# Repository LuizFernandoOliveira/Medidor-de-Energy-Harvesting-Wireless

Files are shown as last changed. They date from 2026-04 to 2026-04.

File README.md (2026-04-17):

# Medidor de Energy Harvesting Wireless




## Descrição
O Medidor de Energy Harvesting Wireless é um circuito eletrônico dedicado a realizar a coleta de dados essenciais para aplicações técnico-científicas relacionadas a Energy Harveting via TEG, PVG, RFG, HEG, WIG, PZT e TC.

<p align="center">
  Imagem1-1
</p>

---

## Descrições técnicas

- Microcontrolador: MSP430FR5949;
- Armazenamento local via micro SD card;
- Envio de dados via UART ou via BLE 5.0;
- Medições de Geradores Termoelétricos (TEG):
  - Temperatura lado Quente;
  - Temperatura lado Frio;
  - Temperatura Ambiente;
- Medições de Geradores Fotovoltaicos (PVG):
  - Medidor de Tensão DC;
  - Medidor de Iluminação;
- Medições de Geradores via Transformadores de Corrente (TCG):
  - Medidor de Tensão AC;
- Medições de Geradores Piezoelétricos (PZT):
  - Medidor de Tensão AC;
  - Medidor de aceleração triaxial;
- Medidções de Geradores Hidroelétricos (HEG):
  - Medidor de Tensão;
  - Medidor de Corrente; 
- Medições de Geradores Eólicos (WIG):
  - Medidor de Tensão;
  - Medidor de Corrente; 
- Medições de Geradores via RF (RFG):
  - Medidor de Tensão;

---

## Estrutura do repositório
Os arquivos de hardware foram desenvolvidos utilizando o KiCad 9.0.
- **`.kicad_pcb`**: Layout da placa de circuito impresso (Board).
- **`.kicad_sch`**: Esquemático eletrônico do sistema (Schematic).
- **`.kicad_pro`**: Gerenciador de projeto do KiCad (Project).

---

## Autor
**Dr. Luiz Fernando Pinto de Oliveira**

*Engenheiro Eletrônico especializado em Sistemas Embarcados e Ultra-Low Power.*
- **Website:** [FAPLO](https://faplo.webnode.page/)
- **LinkedIn:** [lfpo](https://www.linkedin.com/in/lfpo/)

---

Shield: [][cc-by-nc-nd]

This work is licensed under a
[Creative Commons Attribution-NonCommercial-NoDerivs 4.0 International License][cc-by-nc-nd].

[][cc-by-nc-nd]

[cc-by-nc-nd]: http://creativecommons.org/licenses/by-nc-nd/4.0/
[cc-by-nc-nd-image]: https://licensebuttons.net/l/by-nc-nd/4.0/88x31.png
[cc-by-nc-nd-shield]: https://img.shields.io/badge/License-CC%20BY--NC--ND%204.0-lightgrey.svg

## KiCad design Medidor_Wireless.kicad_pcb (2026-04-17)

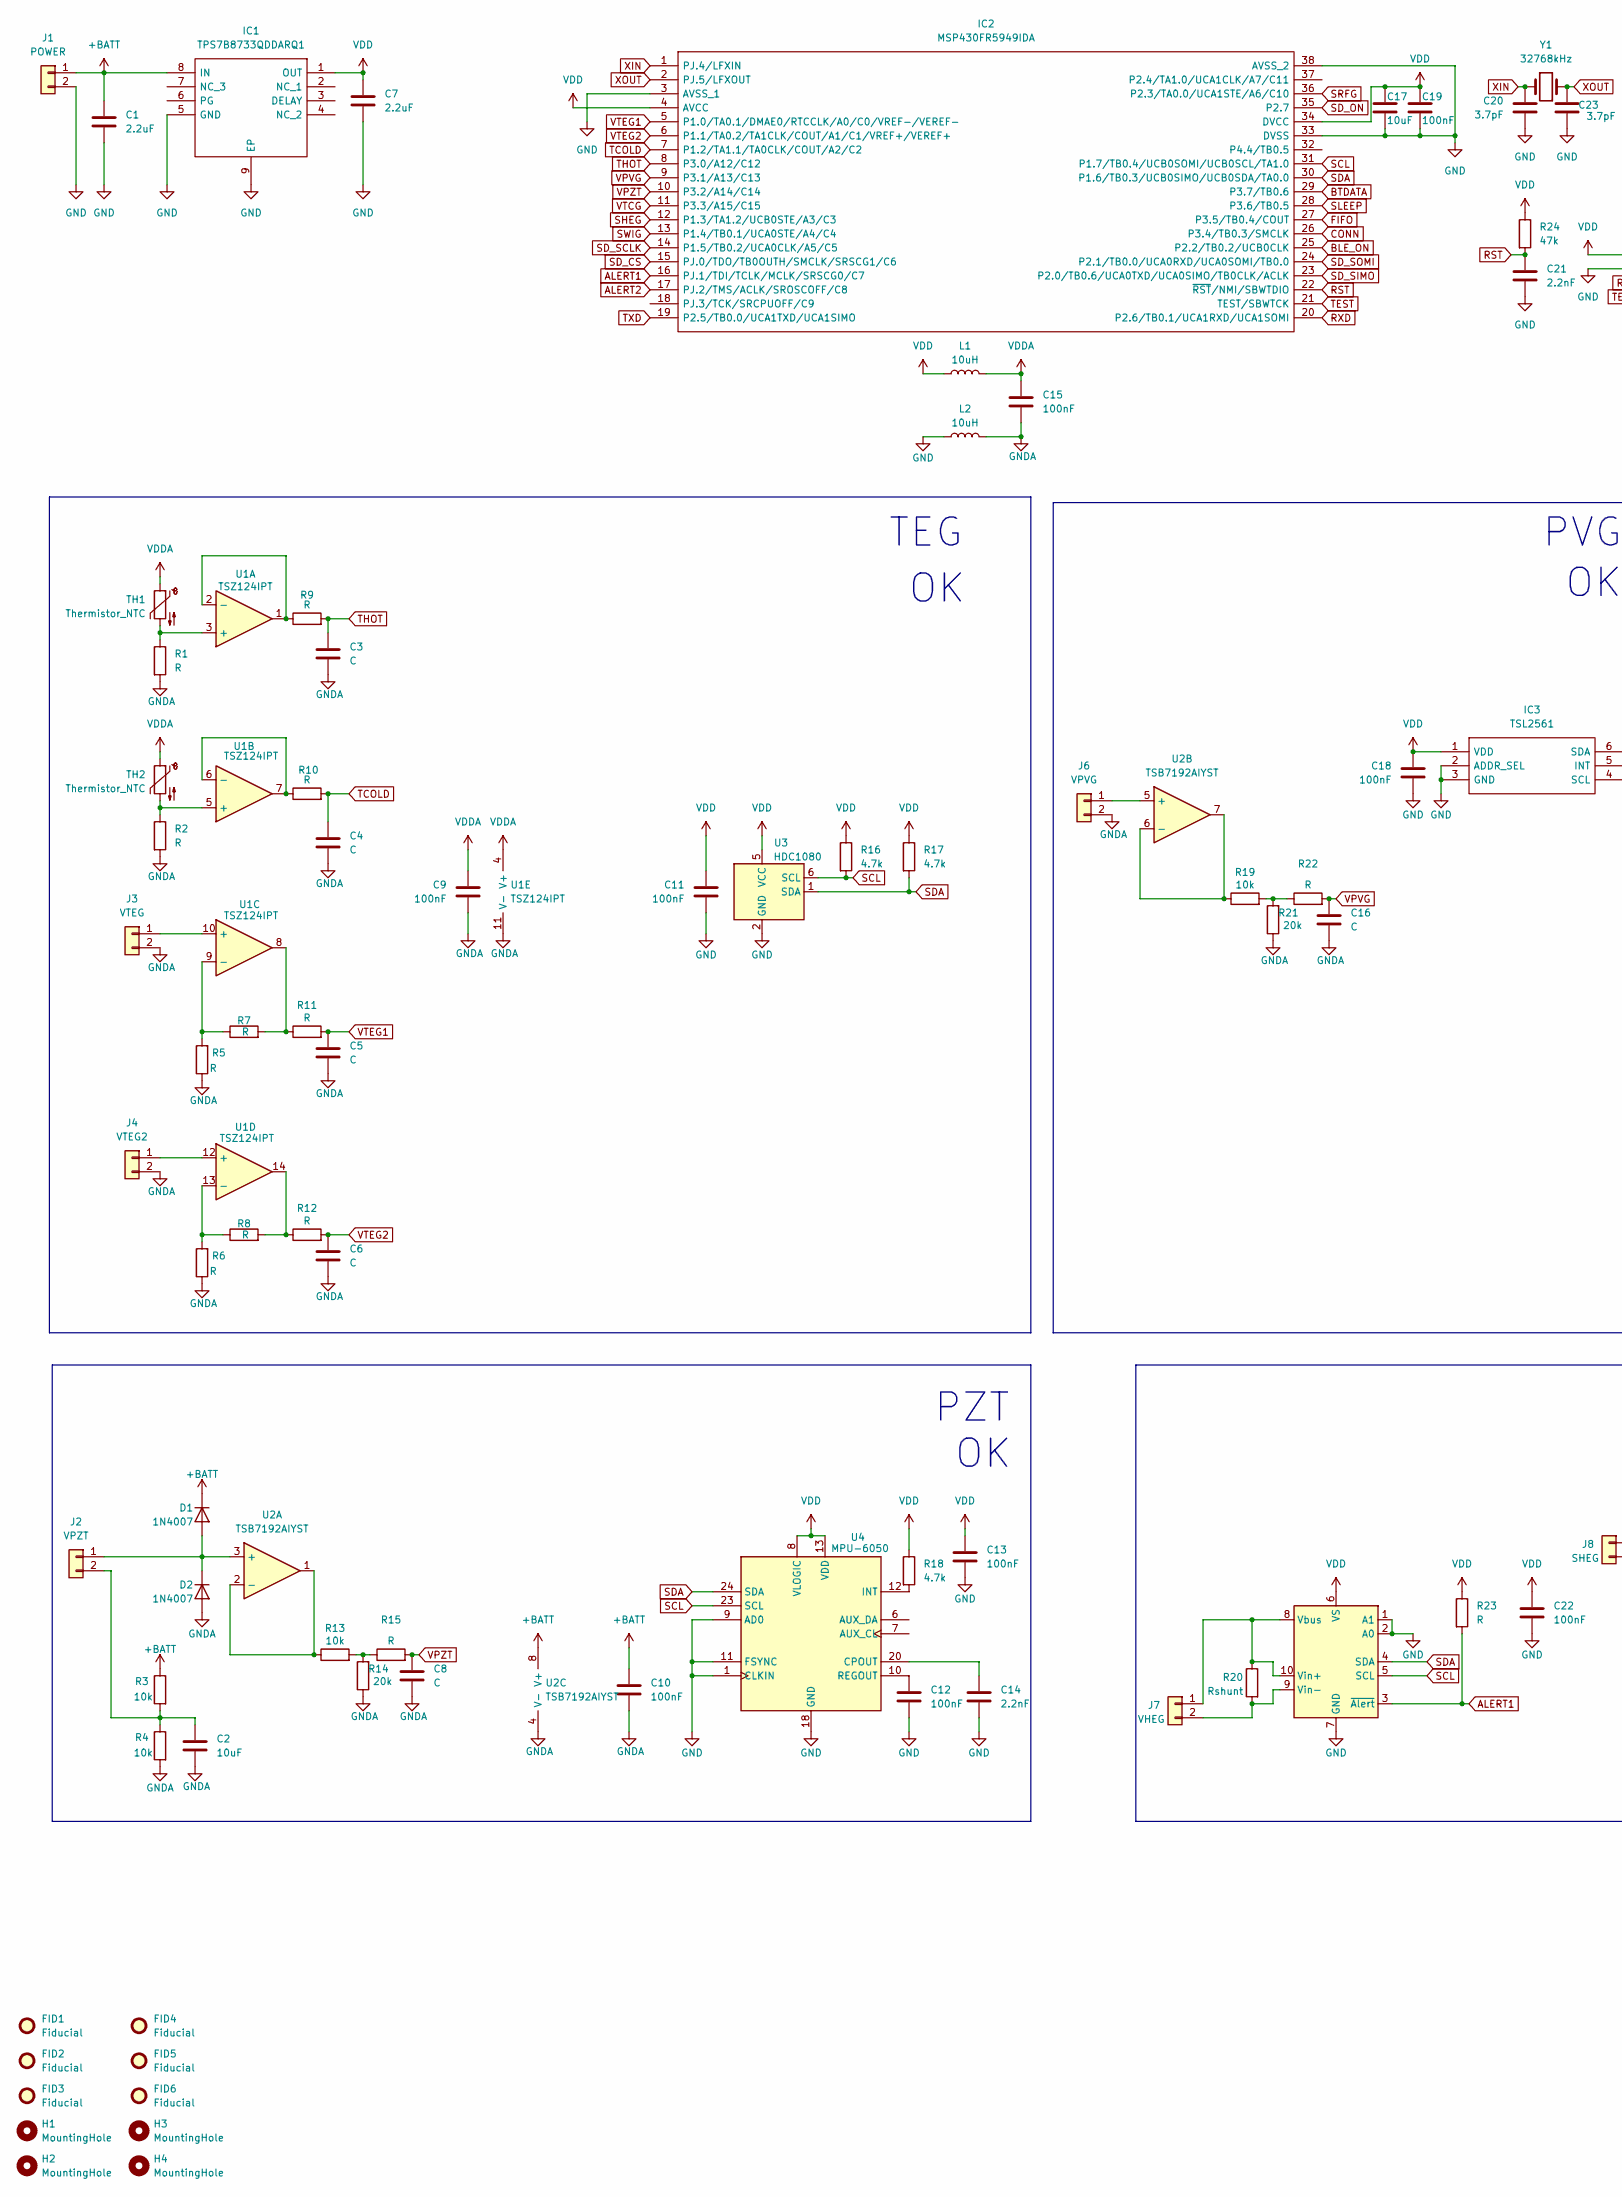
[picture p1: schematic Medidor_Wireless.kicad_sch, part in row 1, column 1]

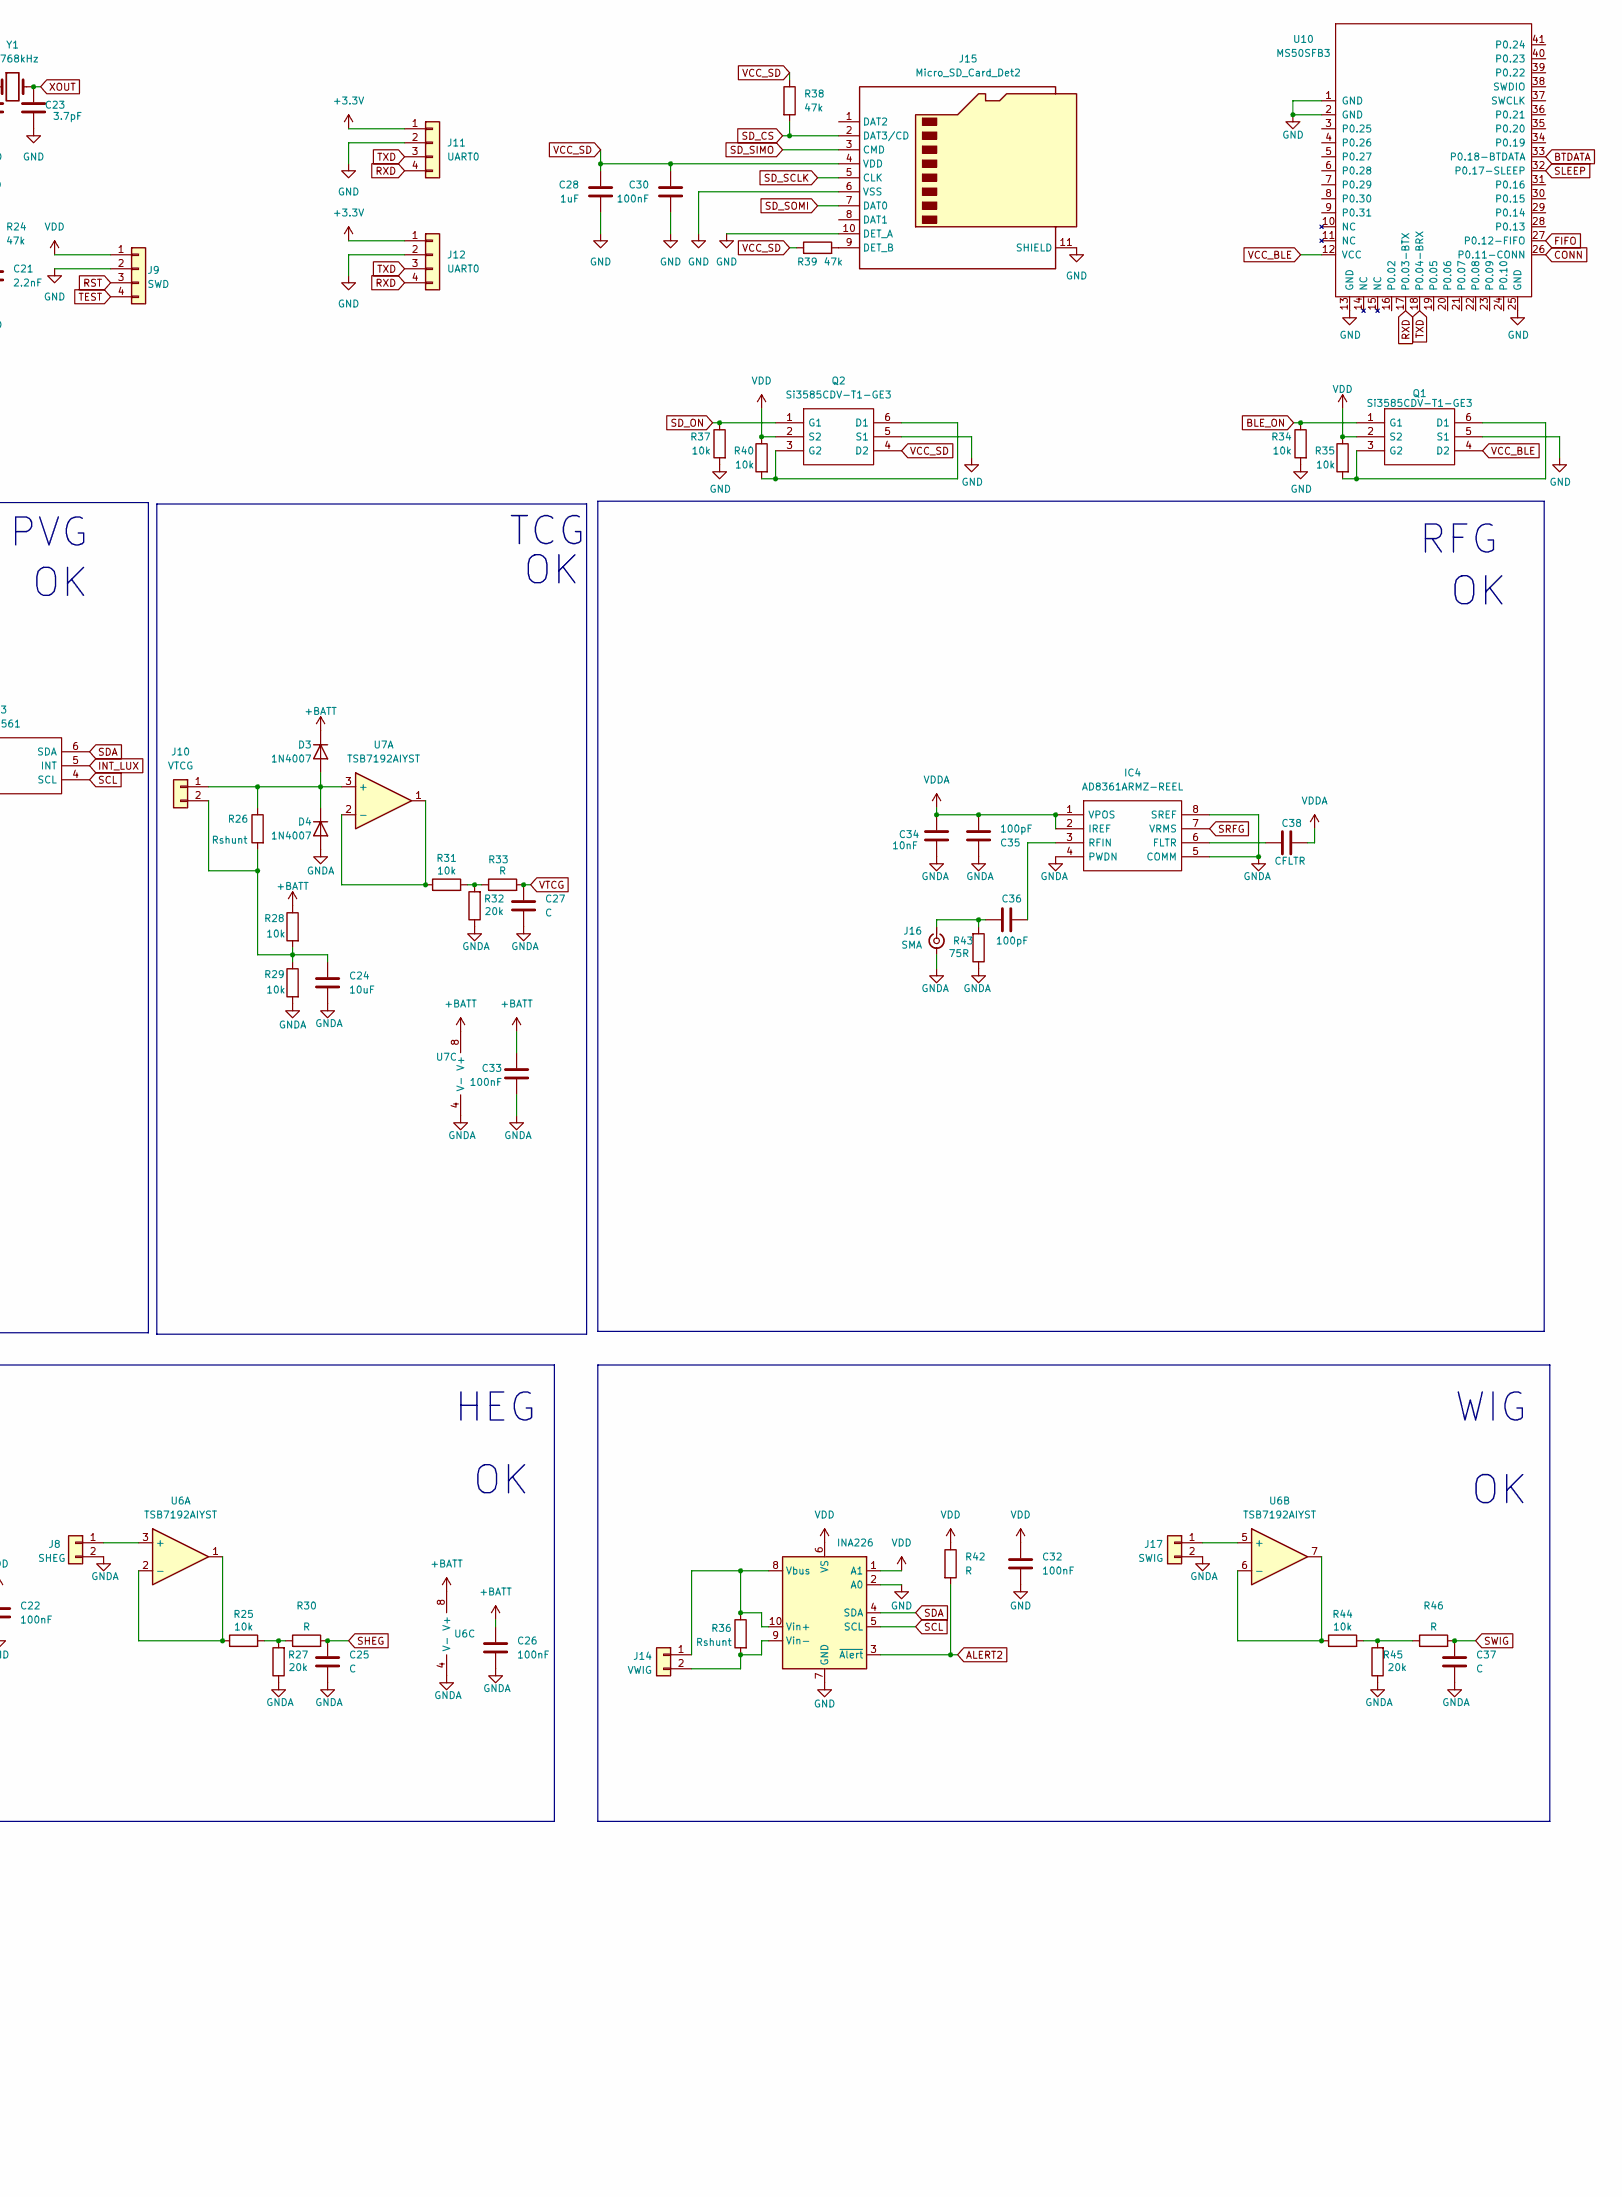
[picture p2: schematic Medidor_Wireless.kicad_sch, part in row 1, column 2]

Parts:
C1, C7: 2.2uF; C_0805_2012Metric
C2, C17, C24: 10uF; C_0805_2012Metric
C3, C4, C5, C6, C8, C16, C25, C27, C37: C; C_0805_2012Metric
C9, C10, C11, C12, C13, C15, C18, C19, C22, C26, C30, C32, C33: 100nF; C_0805_2012Metric
C14, C21: 2.2nF; C_0805_2012Metric
C20, C23: 3.7pF; C_0805_2012Metric
C28: 1uF; C_0805_2012Metric
C34: 10nF; C_0805_2012Metric
C35, C36: 100pF; C_0805_2012Metric
C38: CFLTR; C_0805_2012Metric
D1, D2, D3, D4: 1N4007; D_SOD-123
FID1, FID2, FID3, FID4, FID5, FID6: Fiducial; Fiducial_1mm_Mask2mm
H1, H2, H3, H4: MountingHole; MountingHole_3.2mm_M3_DIN965
IC1: TPS7B8733QDDARQ1; SOIC127P600X170-9N; Manufacturer_Part_Number TPS7B8733QDDARQ1; Mouser Part Number 595-TPS7B8733QDDARQ1
IC2: MSP430FR5949IDA; SOP65P810X120-38N; Manufacturer_Part_Number MSP430FR5949IDA; Mouser Part Number 595-P430FR5949IDA
IC3: TSL2561; Manufacturer_Part_Number TSL2561; Mouser Part Number N/A
IC4: AD8361ARMZ-REEL; SOP65P490X110-8N; Manufacturer_Part_Number AD8361ARMZ-REEL; Mouser Part Number 584-AD8361ARMZ-R
J1: POWER; PinHeader_1x02_P2.54mm_Vertical
J2: VPZT; PinHeader_1x02_P2.54mm_Vertical
J3: VTEG; PinHeader_1x02_P2.54mm_Vertical
J4: VTEG2; PinHeader_1x02_P2.54mm_Vertical
J6: VPVG; PinHeader_1x02_P2.54mm_Vertical
J7: VHEG; PinHeader_1x02_P2.54mm_Vertical
J8: SHEG; PinHeader_1x02_P2.54mm_Vertical
J9: SWD; PinHeader_1x04_P1.27mm_Vertical
J10: VTCG; PinHeader_1x02_P2.54mm_Vertical
J11: UART0; PinHeader_1x04_P2.54mm_Vertical
J12: UART0; JST_XH_S4B-XH-A_1x04_P2.50mm_Horizontal
J14: VWIG; PinHeader_1x02_P2.54mm_Vertical
J15: Micro_SD_Card_Det2; microSD_HC_Hirose_DM3AT-SF-PEJM5
J16: SMA; SMA_Amphenol_132289_EdgeMount
J17: SWIG; PinHeader_1x02_P2.54mm_Vertical
L1, L2: 10uH; L_0805_2012Metric
Q1, Q2: Si3585CDV-T1-GE3; SOT95P284X110-6N; Manufacturer_Part_Number Si3585CDV-T1-GE3; Mouser Part Number 78-SI3585CDV-T1-GE3
R1, R2, R5, R6, R7, R8, R9, R10, R11, R12, R15, R22, R23, R30, R33, R42, R46: R; R_0805_2012Metric
R3, R4, R13, R19, R25, R28, R29, R31, R34, R35, R37, R40, R44: 10k; R_0805_2012Metric
R14, R21, R27, R32, R45: 20k; R_0805_2012Metric
R16, R17, R18: 4.7k; R_0805_2012Metric
R20, R36: Rshunt; R_1206_3216Metric
R24, R38, R39: 47k; R_0805_2012Metric
R26: Rshunt; R_0805_2012Metric
R43: 75R; R_0805_2012Metric
TH1, TH2: Thermistor_NTC; PinHeader_1x02_P2.54mm_Vertical
U1: TSZ124IPT; SOP65P640X120-14N
U2, U6, U7: TSB7192AIYST; SOP65P490X110-8N
U3: HDC1080; Texas_PWSON-N6
U4: MPU-6050; InvenSense_QFN-24_4x4mm_P0.5mm
U5, U9: INA226; VSSOP-10_3x3mm_P0.5mm
U10: MS50SFB3
Y1: 32768kHz; D_0805_2012Metric

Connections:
+3.3V: J11.1, J12.1
+BATT: C1.1, C10.1, C26.1, C33.1, D1.1 (K), D3.1 (K), IC1.8 (IN), J1.1, R3.1, R28.1, U2.8 (V+), U6.8 (V+), U7.8 (V+)
ALERT1: IC2.16 (PJ.1/TDI/TCLK/MCLK/SRSCG0/C7), R23.2, U5.3 (~Alert)
ALERT2: IC2.17 (PJ.2/TMS/ACLK/SROSCOFF/C8), R42.2, U9.3 (~Alert)
BLE_ON: IC2.25 (P2.2/TB0.2/UCB0CLK), Q1.1 (G1), R34.1
BTDATA: IC2.29 (P3.7/TB0.6), U10.33 (P0.18-BTDATA)
CONN: IC2.26 (P3.4/TB0.3/SMCLK), U10.26 (P0.11-CONN)
FIFO: IC2.27 (P3.5/TB0.4/COUT), U10.27 (P0.12-FIFO)
GND: C1.2, C7.2, C11.2, C12.2, C13.2, C14.2, C17.2, C18.2, C19.2, C20.2, C21.2, C22.2, C23.2, C28.2, C30.2, C32.2, IC1.5 (GND), IC1.9 (EP), IC2.3 (AVSS_1), IC2.33 (DVSS), IC2.38 (AVSS_2), IC3.2 (ADDR_SEL), IC3.3 (GND), J1.2, J9.2, J11.2, J12.2, J15.6 (VSS), J15.10 (DET_A), J15.11 (SHIELD), L2.1, Q1.5 (S1), Q2.5 (S1), R34.2, R37.2, U3.2 (GND), U4.1 (CLKIN), U4.9 (AD0), U4.11 (FSYNC), U4.18 (GND), U5.1 (A1), U5.2 (A0), U5.7 (GND), U9.2 (A0), U9.7 (GND), U10.1 (GND), U10.2 (GND), U10.13 (GND), U10.25 (GND)
GNDA: C2.2, C3.2, C4.2, C5.2, C6.2, C8.2, C9.2, C10.2, C15.2, C16.2, C24.2, C25.2, C26.2, C27.2, C33.2, C34.1, C35.1, C37.2, D2.2 (A), D4.2 (A), IC4.4 (PWDN), IC4.5 (COMM), IC4.8 (SREF), J3.2, J4.2, J6.2, J8.2, J16.2 (Ext), J17.2, L2.2, R1.2, R2.2, R4.2, R5.1, R6.1, R14.1, R21.1, R27.1, R29.2, R32.1, R43.1, R45.1, U1.11 (V-), U2.4 (V-), U6.4 (V-), U7.4 (V-)
INT_LUX: IC3.5 (INT)
unnamed: D1.2 (A), D2.1 (K), J2.1, U2.3 (+)
unnamed: D3.2 (A), D4.1 (K), J10.1, R26.1, U7.3 (+)
unnamed: C38.2, IC4.6 (FLTR)
unnamed: C36.1, IC4.3 (RFIN)
unnamed: C2.1, J2.2, R3.2, R4.1
unnamed: J3.1, U1.10 (+)
unnamed: J4.1, U1.12 (+)
unnamed: J6.1, U2.5 (+)
unnamed: J7.1, R20.1, U5.8 (Vbus), U5.10 (Vin+)
unnamed: J7.2, R20.2, U5.9 (Vin-)
unnamed: J8.1, U6.3 (+)
unnamed: C24.1, J10.2, R26.2, R28.2, R29.1
unnamed: J14.1, R36.1, U9.8 (Vbus), U9.10 (Vin+)
unnamed: J14.2, R36.2, U9.9 (Vin-)
unnamed: J15.9 (DET_B), R39.2
unnamed: C36.2, J16.1 (In), R43.2
unnamed: J17.1, U6.5 (+)
unnamed: Q1.3 (G2), Q1.6 (D1), R35.2
unnamed: Q2.3 (G2), Q2.6 (D1), R40.2
unnamed: R7.2, R11.1, U1.8
unnamed: R8.2, R12.1, U1.14
unnamed: R13.2, R14.2, R15.1
unnamed: R19.2, R21.2, R22.1
unnamed: R25.2, R27.2, R30.1
unnamed: R31.2, R32.2, R33.1
unnamed: R44.2, R45.2, R46.1
unnamed: R1.1, TH1.2, U1.3 (+)
unnamed: R9.1, U1.1, U1.2 (-)
unnamed: R2.1, TH2.2, U1.5 (+)
unnamed: R10.1, U1.6 (-), U1.7
unnamed: R5.2, R7.1, U1.9 (-)
unnamed: R6.2, R8.1, U1.13 (-)
unnamed: R13.1, U2.1, U2.2 (-)
unnamed: R19.1, U2.6 (-), U2.7
unnamed: C14.1, U4.20 (CPOUT)
unnamed: R18.2, U4.12 (INT)
unnamed: C12.1, U4.10 (REGOUT)
unnamed: R25.1, U6.1, U6.2 (-)
unnamed: R44.1, U6.6 (-), U6.7
unnamed: R31.1, U7.1, U7.2 (-)
RST: C21.1, IC2.22 (~RST/NMI/SBWTDIO), J9.3, R24.2
RXD: IC2.20 (P2.6/TB0.1/UCA1RXD/UCA1SOMI), J11.4, J12.4, U10.17 (P0.03-BTX)
SCL: IC2.31 (P1.7/TB0.4/UCB0SOMI/UCB0SCL/TA1.0), IC3.4 (SCL), R16.2, U3.6 (SCL), U4.23 (SCL), U5.5 (SCL), U9.5 (SCL)
SDA: IC2.30 (P1.6/TB0.3/UCB0SIMO/UCB0SDA/TA0.0), IC3.6 (SDA), R17.2, U3.1 (SDA), U4.24 (SDA), U5.4 (SDA), U9.4 (SDA)
SD_CS: IC2.15 (PJ.0/TDO/TB0OUTH/SMCLK/SRSCG1/C6), J15.2 (DAT3/CD), R38.2
SD_ON: IC2.35 (P2.7), Q2.1 (G1), R37.1
SD_SCLK: IC2.14 (P1.5/TB0.2/UCA0CLK/A5/C5), J15.5 (CLK)
SD_SIMO: IC2.23 (P2.0/TB0.6/UCA0TXD/UCA0SIMO/TB0CLK/ACLK), J15.3 (CMD)
SD_SOMI: IC2.24 (P2.1/TB0.0/UCA0RXD/UCA0SOMI/TB0.0), J15.7 (DAT0)
SHEG: C25.1, IC2.12 (P1.3/TA1.2/UCB0STE/A3/C3), R30.2
SLEEP: IC2.28 (P3.6/TB0.5), U10.32 (P0.17-SLEEP)
SRFG: IC2.36 (P2.3/TA0.0/UCA1STE/A6/C10), IC4.7 (VRMS)
SWIG: C37.1, IC2.13 (P1.4/TB0.1/UCA0STE/A4/C4), R46.2
TCOLD: C4.1, IC2.7 (P1.2/TA1.1/TA0CLK/COUT/A2/C2), R10.2
TEST: IC2.21 (TEST/SBWTCK), J9.4
THOT: C3.1, IC2.8 (P3.0/A12/C12), R9.2
TXD: IC2.19 (P2.5/TB0.0/UCA1TXD/UCA1SIMO), J11.3, J12.3, U10.18 (P0.04-BRX)
VCC_BLE: Q1.4 (D2), U10.12 (VCC)
VCC_SD: C28.1, C30.1, J15.4 (VDD), Q2.4 (D2), R38.1, R39.1
VDD: C7.1, C11.1, C13.1, C17.1, C18.1, C19.1, C22.1, C32.1, IC1.1 (OUT), IC2.4 (AVCC), IC2.34 (DVCC), IC3.1 (VDD), J9.1, L1.1, Q1.2 (S2), Q2.2 (S2), R16.1, R17.1, R18.1, R23.1, R24.1, R35.1, R40.1, R42.1, U3.5 (VCC), U4.8 (VLOGIC), U4.13 (VDD), U5.6 (VS), U9.1 (A1), U9.6 (VS)
VDDA: C9.1, C15.1, C34.2, C35.2, C38.1, IC4.1 (VPOS), IC4.2 (IREF), L1.2, TH1.1, TH2.1, U1.4 (V+)
VPVG: C16.1, IC2.9 (P3.1/A13/C13), R22.2
VPZT: C8.1, IC2.10 (P3.2/A14/C14), R15.2
VTCG: C27.1, IC2.11 (P3.3/A15/C15), R33.2
VTEG1: C5.1, IC2.5 (P1.0/TA0.1/DMAE0/RTCCLK/A0/C0/VREF-/VER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), R11.2
VTEG2: C6.1, IC2.6 (P1.1/TA0.2/TA1CLK/COUT/A1/C1/VREF+/VERE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), R12.2
XIN: C20.1, IC2.1 (PJ.4/LFXIN), Y1.1
XOUT: C23.1, IC2.2 (PJ.5/LFXOUT), Y1.2

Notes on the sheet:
WIG
TCG
TEG
PVG
RFG
HEG
PZT

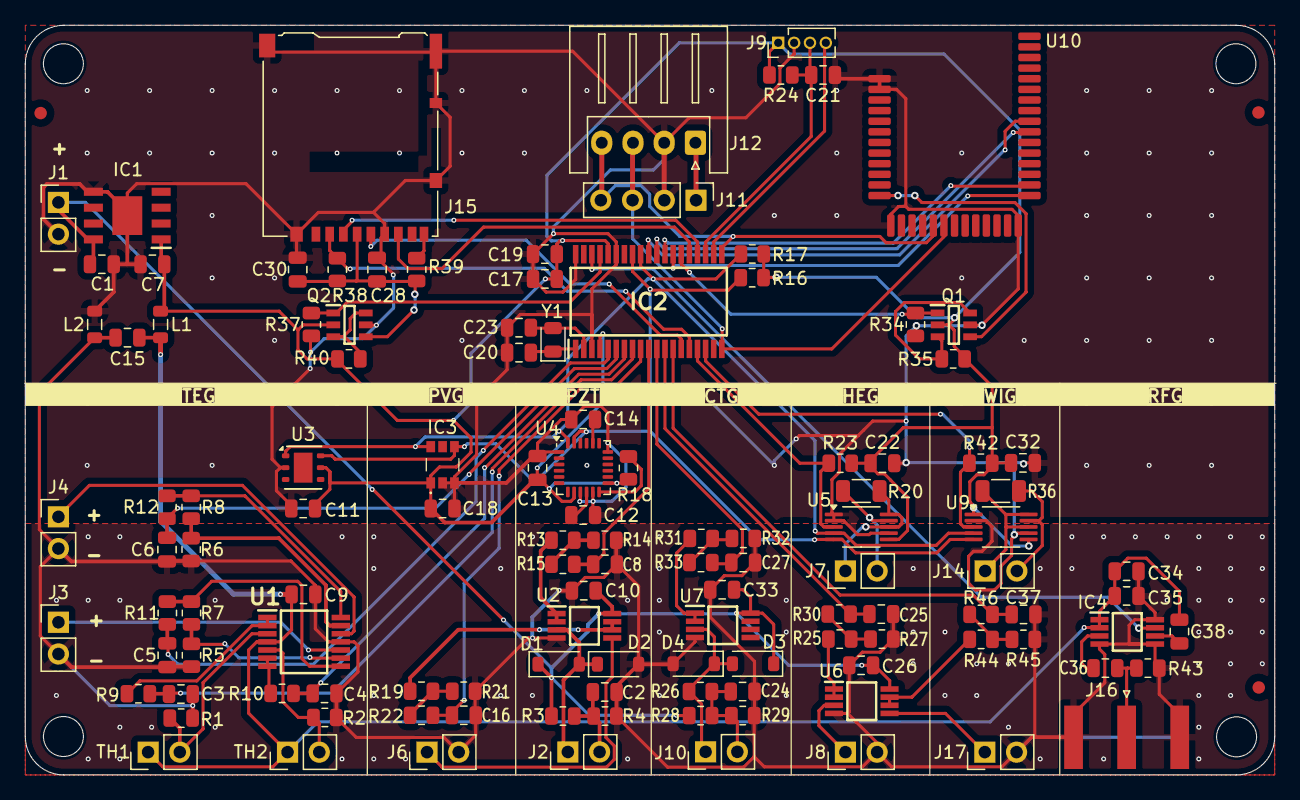
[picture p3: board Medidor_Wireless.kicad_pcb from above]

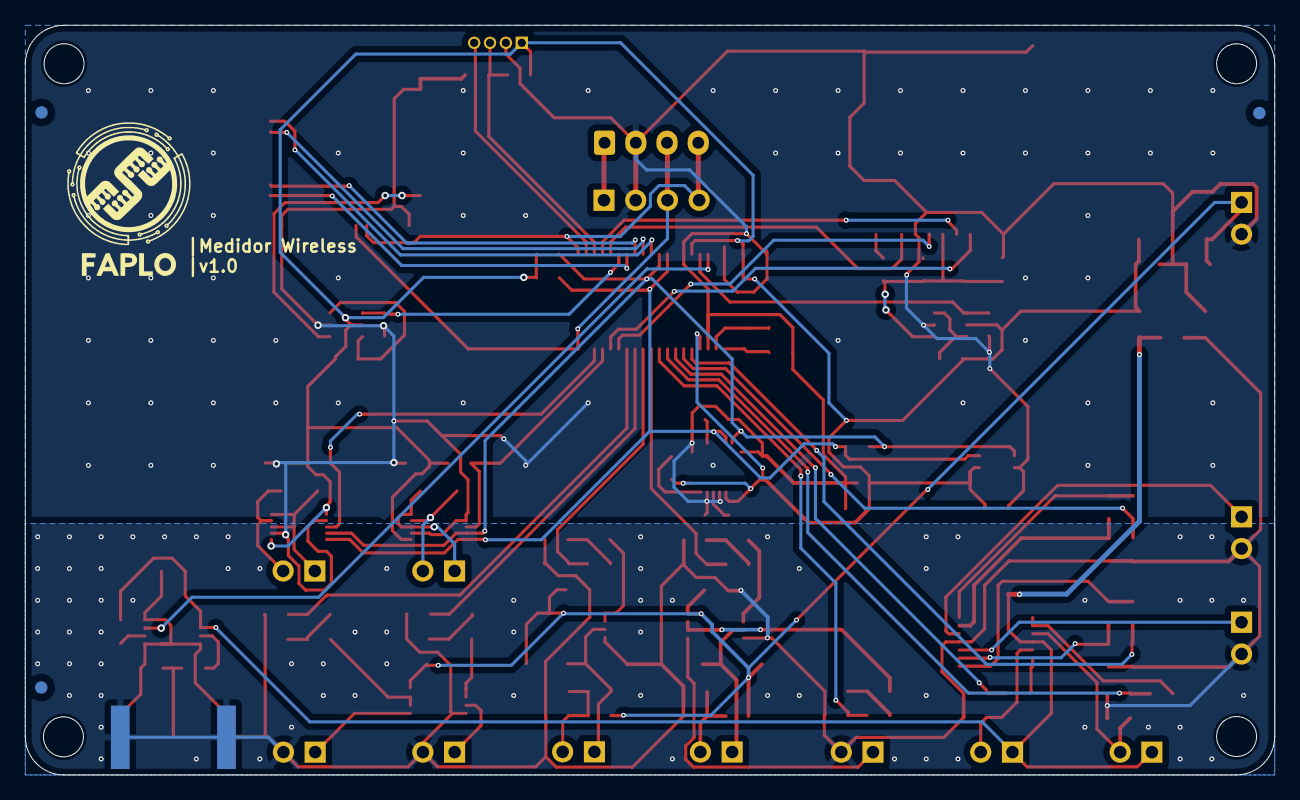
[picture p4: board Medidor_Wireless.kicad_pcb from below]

Board: 2 copper layers, 100.0 x 60.0 mm, 130 parts (3 on the bottom side), 78 nets.

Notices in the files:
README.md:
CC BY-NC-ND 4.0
